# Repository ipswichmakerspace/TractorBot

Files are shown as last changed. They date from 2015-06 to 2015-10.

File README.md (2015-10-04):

# TractorBot 2014
Code and hardware files for TractorBot, the winner of the 2014 [PiWars](http://piwars.org) competition run by the CamJam team in Cambridge. The code, schematics and hardware files provided are exactly as the robot ran on the day of the 2014 competition. There is certainly room for improvement, and we expect this to be used as a solid base to start from, rather than a finished polished product. It worked for us, but your mileage may vary.

If you have any questions please use our [forums](http://forums.ipswichmakerspace.com) 

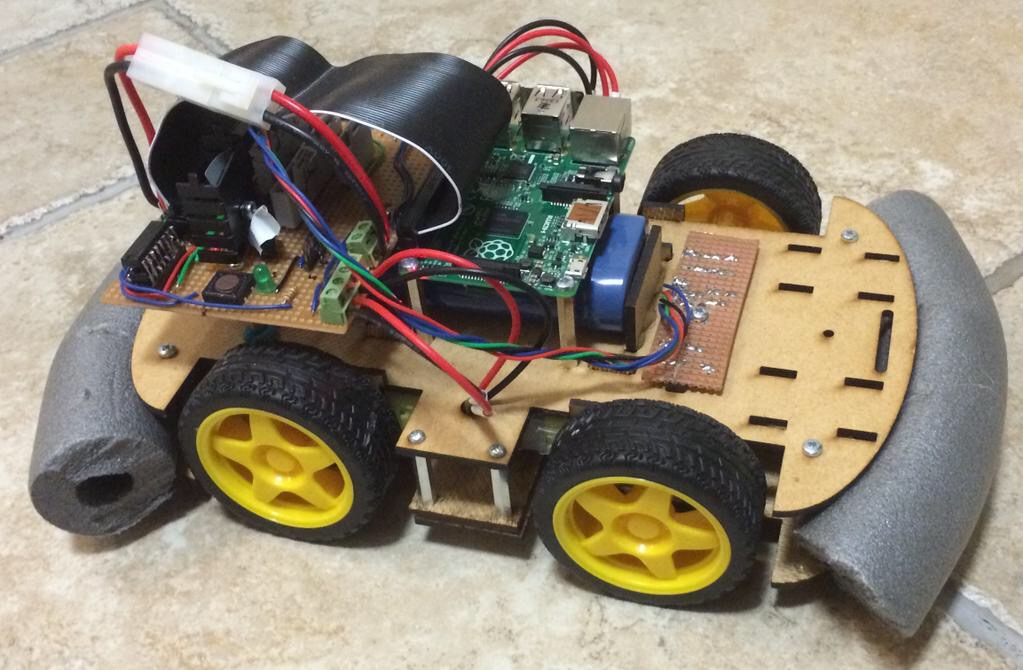
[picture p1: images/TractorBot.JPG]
TractorBot


The **hardware**, files of which can be found in the hardware folder are licensed under the CERN Open Hardware Licence v1.2, the license can be found in the directory /hardware/license. this is essentially an open source licence which can be used for all purposes provided attribution is given to Ipswich Makerspace.

The chassis is designed to be laser cut from a material measuring 3mm thick. Perspex could be used, but for cost we used hard board and this worked very well.

Our chassis was cut by [Cedarcroft Productions](http://www.cedarcroftproductions.com/) based in Ipswich.

Many of the parts for TractorBot were provided by our sponsor [Rapid Electronics](http://www.rapidonline.com/)

The code and schematics for the interface board are now in this repository.  We have kept the information short and to the point, for example we do not provide instructions for the construction of the chassis,  this is quite self explanitory.  However if we get a few requests for more information and if time allows we may build on this information.

For the electronics, including Fritzing diagrams, Ki-CAD schematics and information how it all works click [here](electronics/electronics.md)

For a description of the hardware click [here](hardware/hardware.md)

Hardware designed by Keith Ellis

Software written by Phil Willis in C++
on behalf of [Ipswich Makerspace](http://ipswichmakerspace.com)

----

If you have any queries or questions please raise on the Ipswich Makerspace [forums](http://forums.ipswichmakerspace.com/)

**TractorBot** is a Trademark of Ipswich Makerspace

This is provided on an "as-is" basis and all rights are reserved, no warranty is provided and no responsibility will be taken for any harm or damage caused whatsoever.

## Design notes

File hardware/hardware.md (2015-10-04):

#Hardware#

##General Description##
TractorBot was designed to be cheap, we competed in the £75 and under catergory, and we were very honest with out pricing.  As a result we built our own interface board [see electronics](../electronics/electronics.md), and designed and lasercut our own chassis.

The chassis was a simple design and consists of a single plate with four cheap motors attached to the plate with 'T' connection brackets.  We were always keen to do well in the obstacle course challege so we went with four wheel drive and kept the ground clearance as high as possible.  To aid the ground clearance we did not install a second plate beaneath the motors, instead, we installed a small strengthening plate between the four wheels.

The image below shows TractorBot during development. 

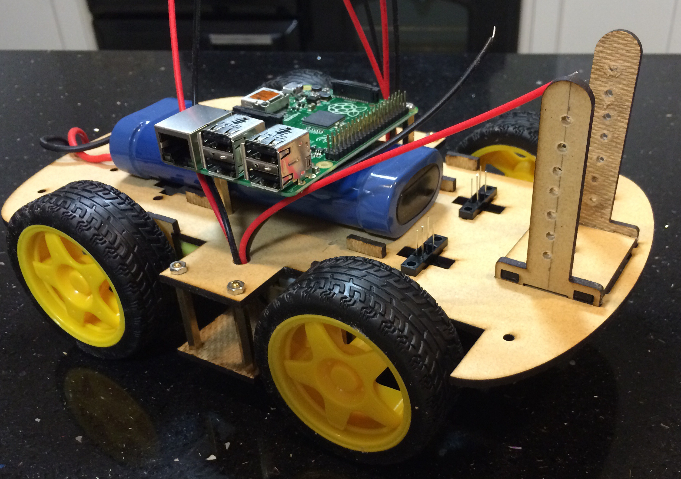
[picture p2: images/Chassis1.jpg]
Chassis


You can see the main plate, with the small strenghening plate below betwen the wheels, this was installed on 25mm long stand-offs.  On top of the plate there is a standard radio controlled car battery, which runs at 7.2v, the Raspoberry Pi was installed above the battery on stand-offs.  At the front we developed a universal mount system which allowed us to add and remove various sensors or attachments to suit each challenge.

The attachments we made are as follows:

* Ultrasonic sensor mount, we also mounted an IR distance sensor on this too.  Both for the proximity challenge

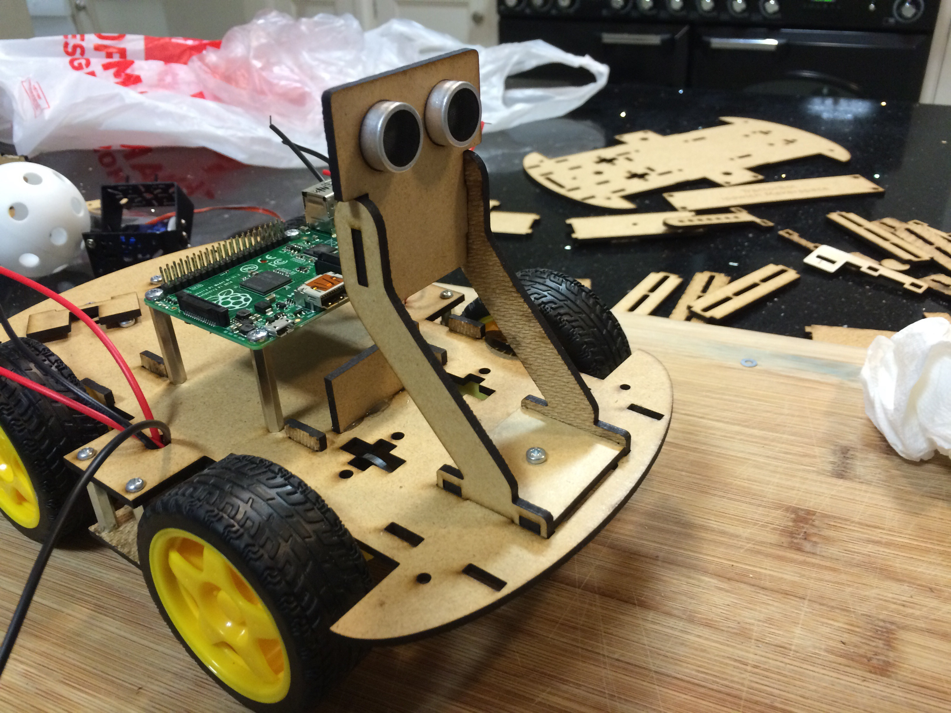
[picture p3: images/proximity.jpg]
Proximity


* Ball catcher, for the golf challenge

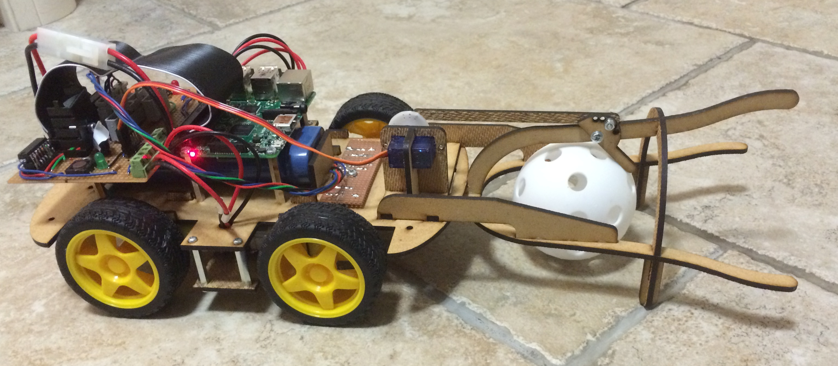
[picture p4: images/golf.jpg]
Golf


* Line following sensors, for the line following challenge

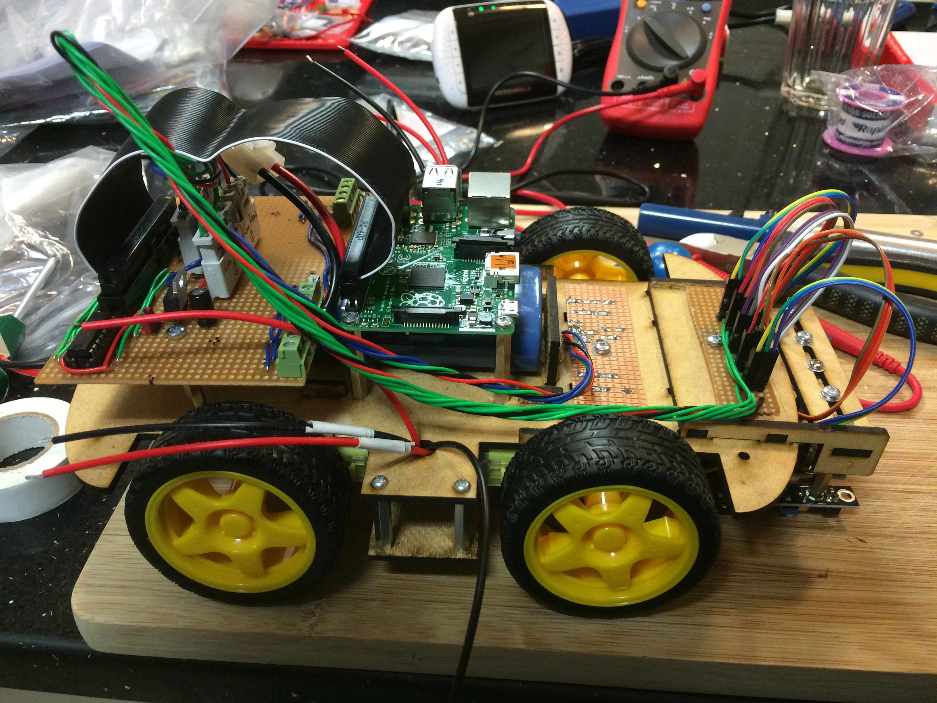
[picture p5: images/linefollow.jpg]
Line Folow


* Sumo suit, for the Sumo challenge

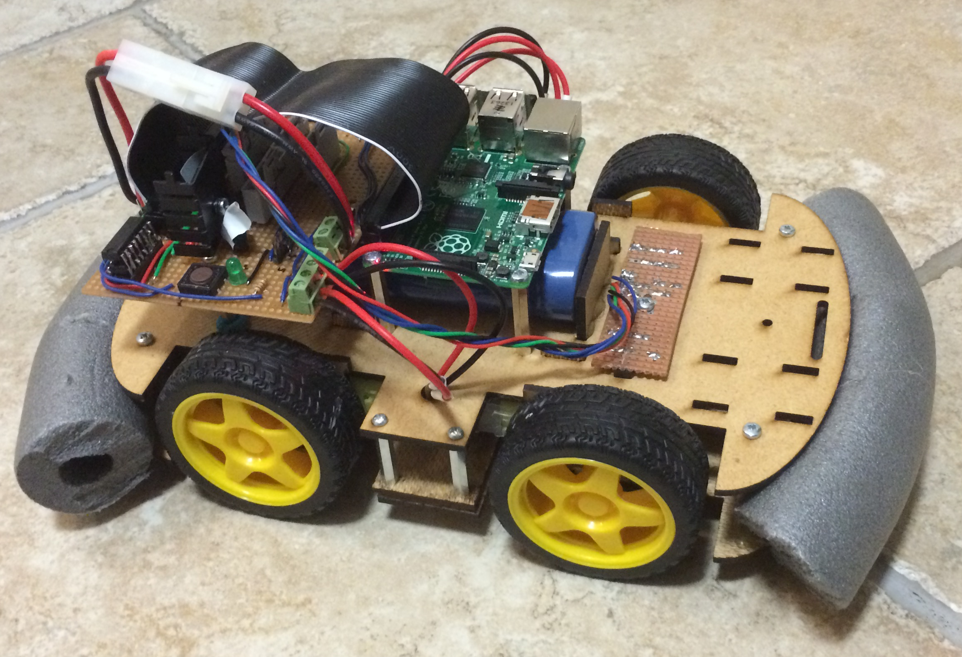
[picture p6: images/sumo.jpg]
Sumo


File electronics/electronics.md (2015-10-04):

#Electronics#

##Overview##
**TractorBot** electronics is contained on a main interface board.  The interface board features the following features:

- 20 x 2 shrouded header to allow connection to the Raspberry Pi with a 40 way ribbon cable
- 5 volt low dropout voltage regulator
- L293D motor driver
- two LED's and buttons to allow selection of mode - described in the software section
- terminal connectors to conect 7.2v RC car battery
- terminal connectors to connect four motors
- jumper to connect/disconnect power to the Pi
- various headers
    - serial debug connection
    - motor encoders
    - line follower sensors
    - ultra sonic sensor
    - IR object detection sensor
    - servo
    
We have provided the following information:

- A general description on how the the robot works (below)
- Interface board map, showing the features of the board, where they are and also Raspberry Pi pin numbers
- Fritzing file and image, this is not exactly the same as the board as entered into the compitition, mainly because we found it hard to find particualar components in Fritzing. We have also omitted the swithc to disable the rear motors, we did not use this feature in the competition, the robot ran in 4WD at all times.
- We also plan to provide Ki-CAD schematics, but these have not been produced yet.

It should be noted the this documentation for the electronics has been prepared approximately nine months after the interface boards were actually made.  The board got build over a number of weeks and was not planned in advace, therefore the layout is probably not optimum.

##Interface board##
The interface board is build on strip board, when using strip board is is often necessary to break the tracks to allow a single track to be used for two signals, particually the tracks connecting the 20 x 2 header has to be broken along the centre to prevent the two rows of pins from being connected.  All the breaks can be seen in the Fritzing file, but to make it clear I have provided a image of the strip board alone.

###Fritzing Stripboard layout###
showing broken tracks

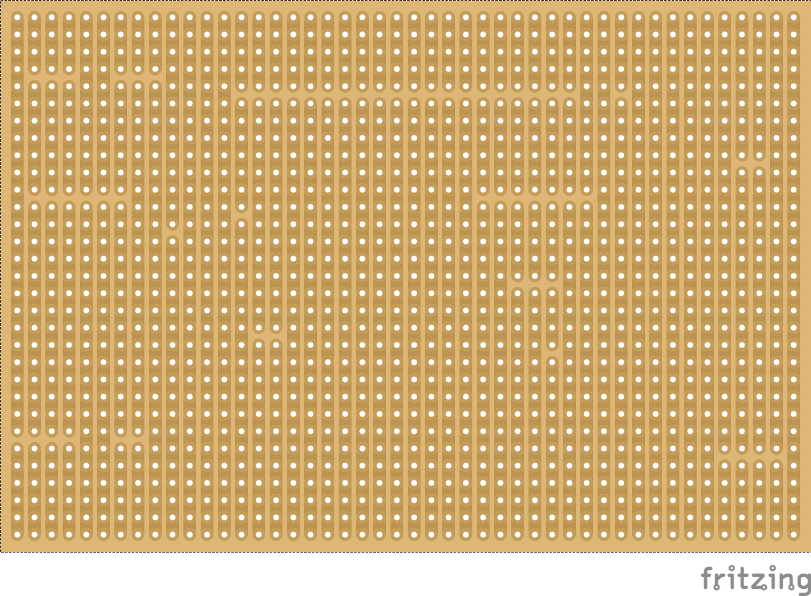
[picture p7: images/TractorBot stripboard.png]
stripbaord


###Fritzing interface board layout###
complete with all wiring

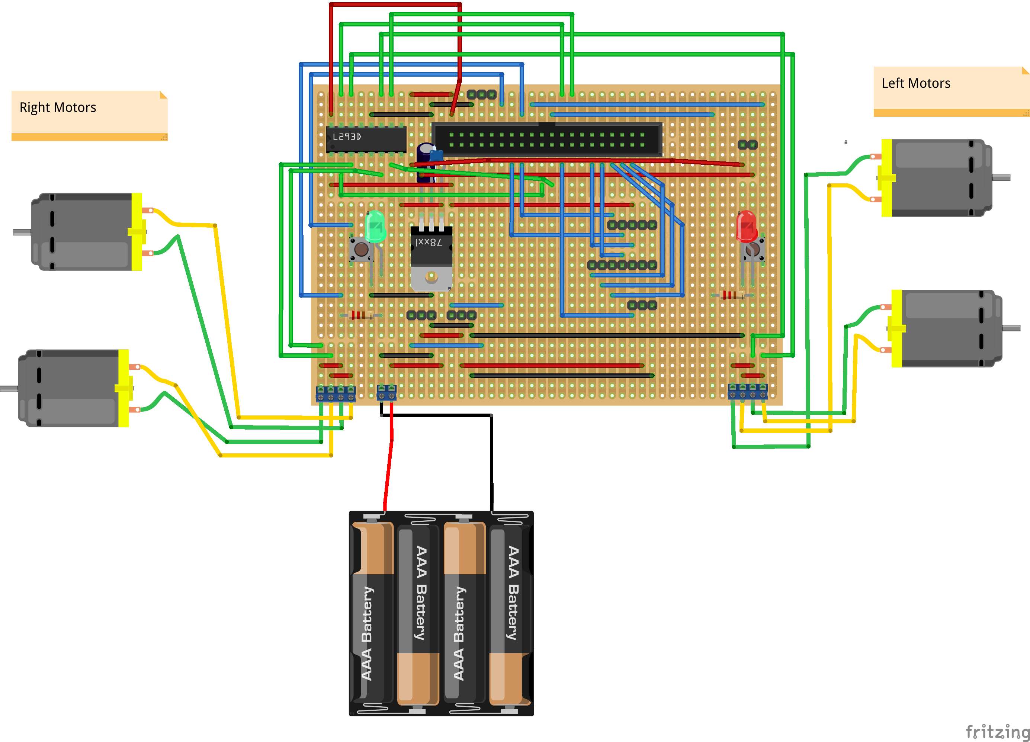
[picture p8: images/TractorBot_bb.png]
Interface board


###Interface board map###
showing header and terminal connection pin outs
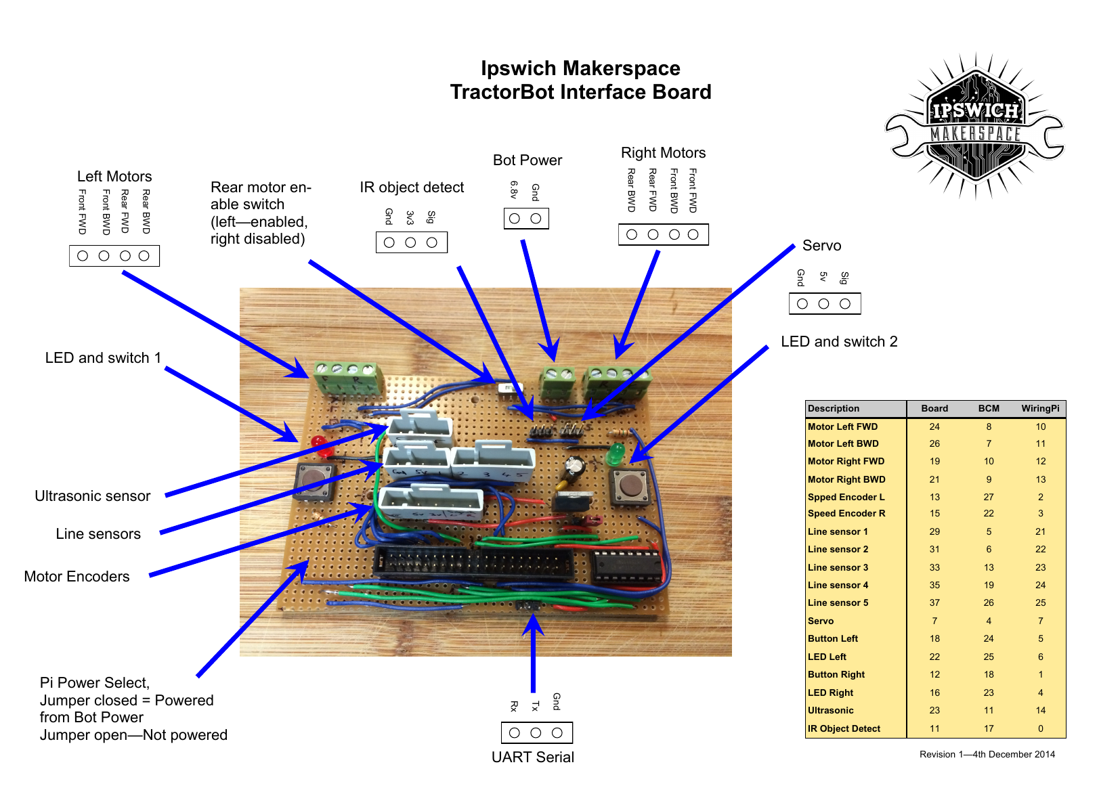
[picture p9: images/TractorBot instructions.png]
Interface board map


[Fritzing file](TractorBot.fzz), note this has been produced after the process of making the actual stripboard, I have done a thorough review to ensure as far as possible that it is correct but there may be a mistake which has been missed.  Please check carefully yourself before use.  I do not take any responsibility for a damaged Pi as a result of using this file.

##20 x 2 shrouded header##
I got this shrouded header and the ribbon cable from an Adafruit Pi cobbler, I think I got mine from [Pimoroni](http://shop.pimoroni.com/products/adafruit-pi-t-cobbler-plus-kit-breakout-for-raspberry-pi-b).  Pin one is shown on all images here to the top right, i.e the end closest to the motor driver is pin 1.  To break the tracks between the two rows of pins I used a stanley knife with a steel ruler and run the knife along the board several times to ensure I cut the tracks properly.  I also checked that each track had been cut using a multi meter on the continuity setting.  vThis should be done before the header is soldered, it would be very dificult to cur the tracks afterwards.

##5v voltage regulator##
To ensure we had enough power for the motors a 7.2 volt radio contorl car battery was used.  We got ours from [Rapid Electronics](http://www.rapidonline.com/Education/VEX-7-2V-Robot-Battery-NiMH-3000mAh-70-6237).  This ensured we had plenty of power for the motors but 7.2v would fry a Pi, to enable this battery to be powered from the same battery and to avoid putting an addition 5v battery on board we used a 5v voltage regulator.  This takes the 7.2v and puts out 5v for use by the Pi.  The voltage regulator is a thre pin device and can be seen adjacent to the right hand button and green LED.  

The part number we used was the National Semiconductor LM2940, data sheet can be found [here](7427.pdf), as can be seen on the data sheet this also requires two capacitors.  It will not work without the capacitors (trust me, I tried it). a 0.41 micro farrade is required between the Vin and ground and a 22 micro farrade capacitor is required between Vout and ground.

In our case, Vin will be the 7.2 volt supply and Vout will be the 5v coming out, which we then feed into the Pi.

##Motor driver##
We used a L293D motor driver to drive all four motors.  The current draw of the motors four motors is quite close to limits of the driver chip but it should be ok.  Pin 1 for the motor driver is to the top right as shown in the images, i.e. pin 1 is on the edge of the strip board.  The data sheet can be found [here](l293d.pdf).  There are many tutorials one the internet showing how to use these chips so I will not cover it here, sufice to say, it takes the low input from the Pi GPIO pins and out puts the 7.2v direct from the battery straight to the motor.

##LED's and buttons##
The interface board has two LED's and buttons.  These are used to navigate through the programs menu system.  The red button is pressed a number of times depending upon the mode required.  the red LED indicated how many times the button has been pressed by flashing.  The button adjacent to the green button selects the desired mode.  More about this will be in the software section.

##Terminals and headers##
All the pins are identified on the interface board map, shown above.  The only exeption being the jumper to contorl the power to the Pi.  I moved this after making the map to make it more accessable, however the Fritzing file and the label on the map are showin in the correct location.  To use this the 7.2v battery must be plugged in, then to power the Pi the jumper is placed on this header.  The Pi will be powered and boot up and automatically start the TractorBot program.

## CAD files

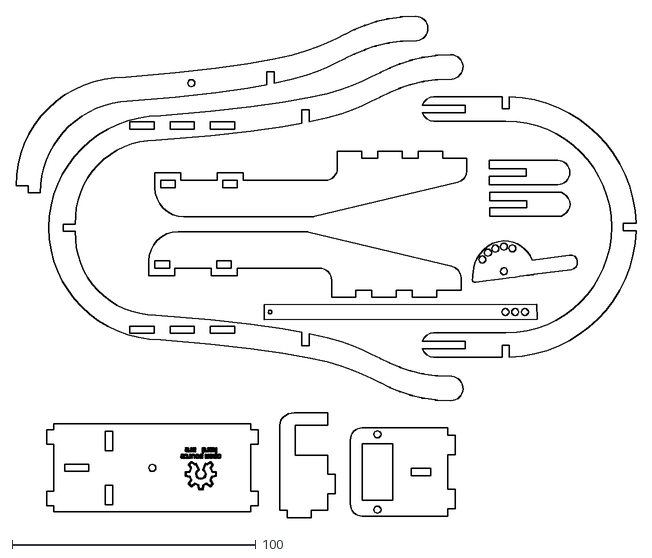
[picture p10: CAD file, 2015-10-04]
hardware/Source Files/Ball catcher.dxf
254.4 x 205.8

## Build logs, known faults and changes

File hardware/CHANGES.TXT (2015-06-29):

This is the original documentation.  If you make changes please detail them here and distribute this document with the modified files and the CERN OSH License v1.2

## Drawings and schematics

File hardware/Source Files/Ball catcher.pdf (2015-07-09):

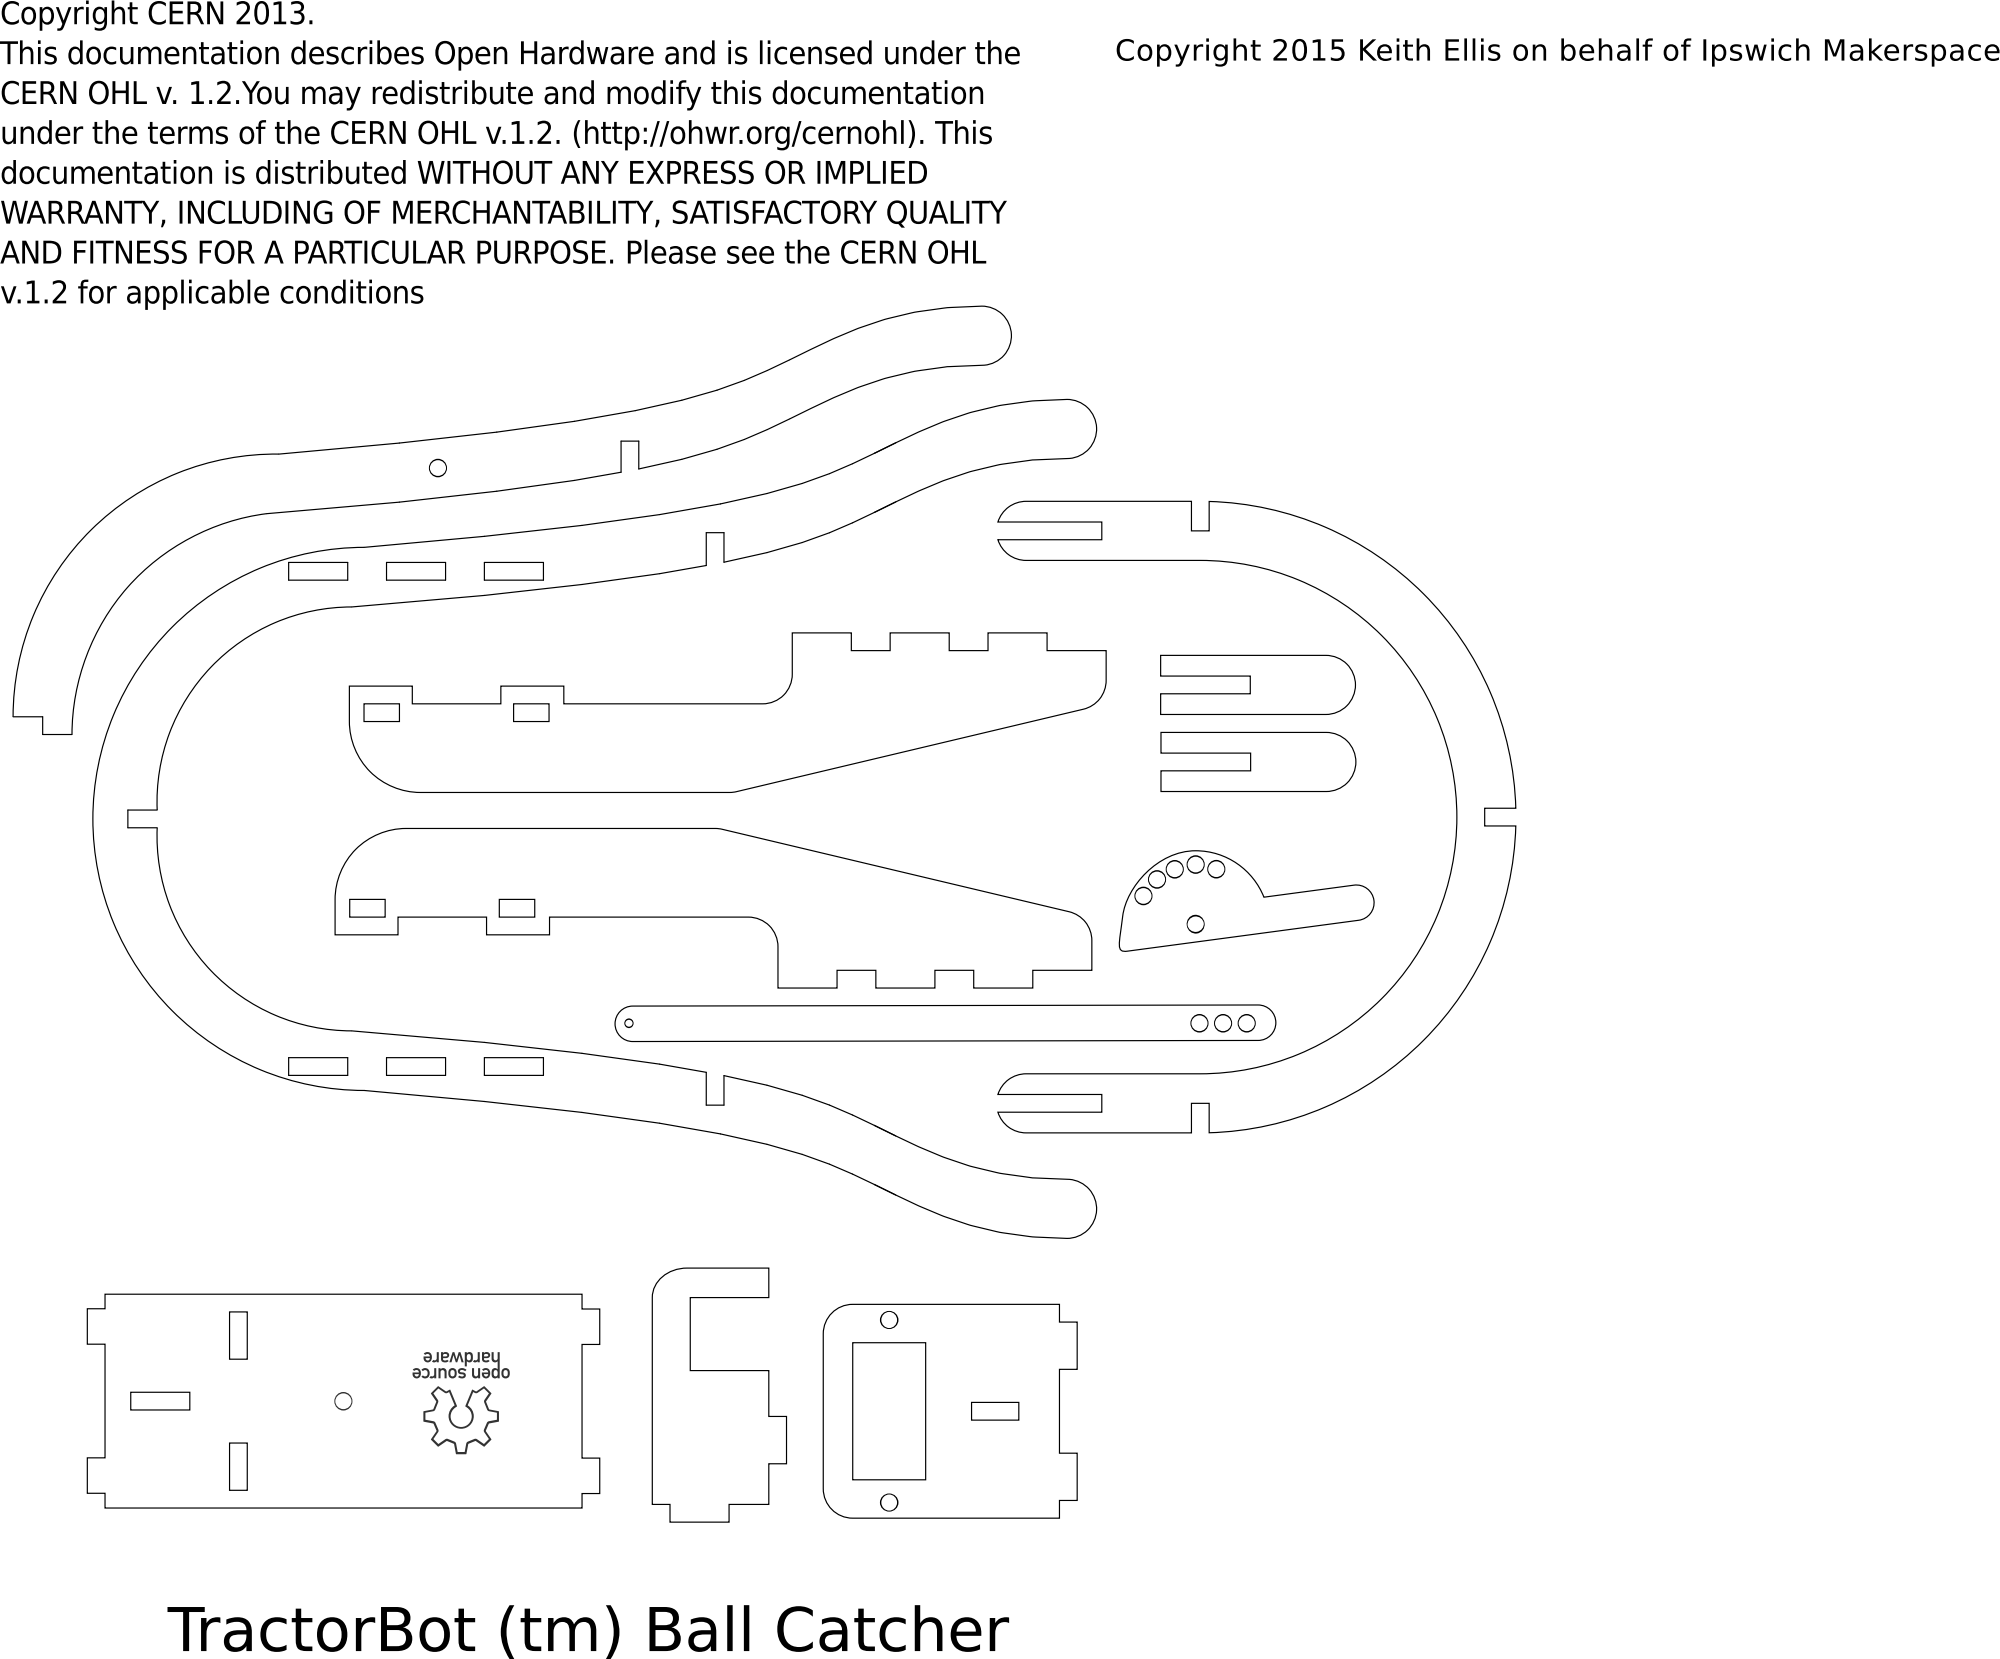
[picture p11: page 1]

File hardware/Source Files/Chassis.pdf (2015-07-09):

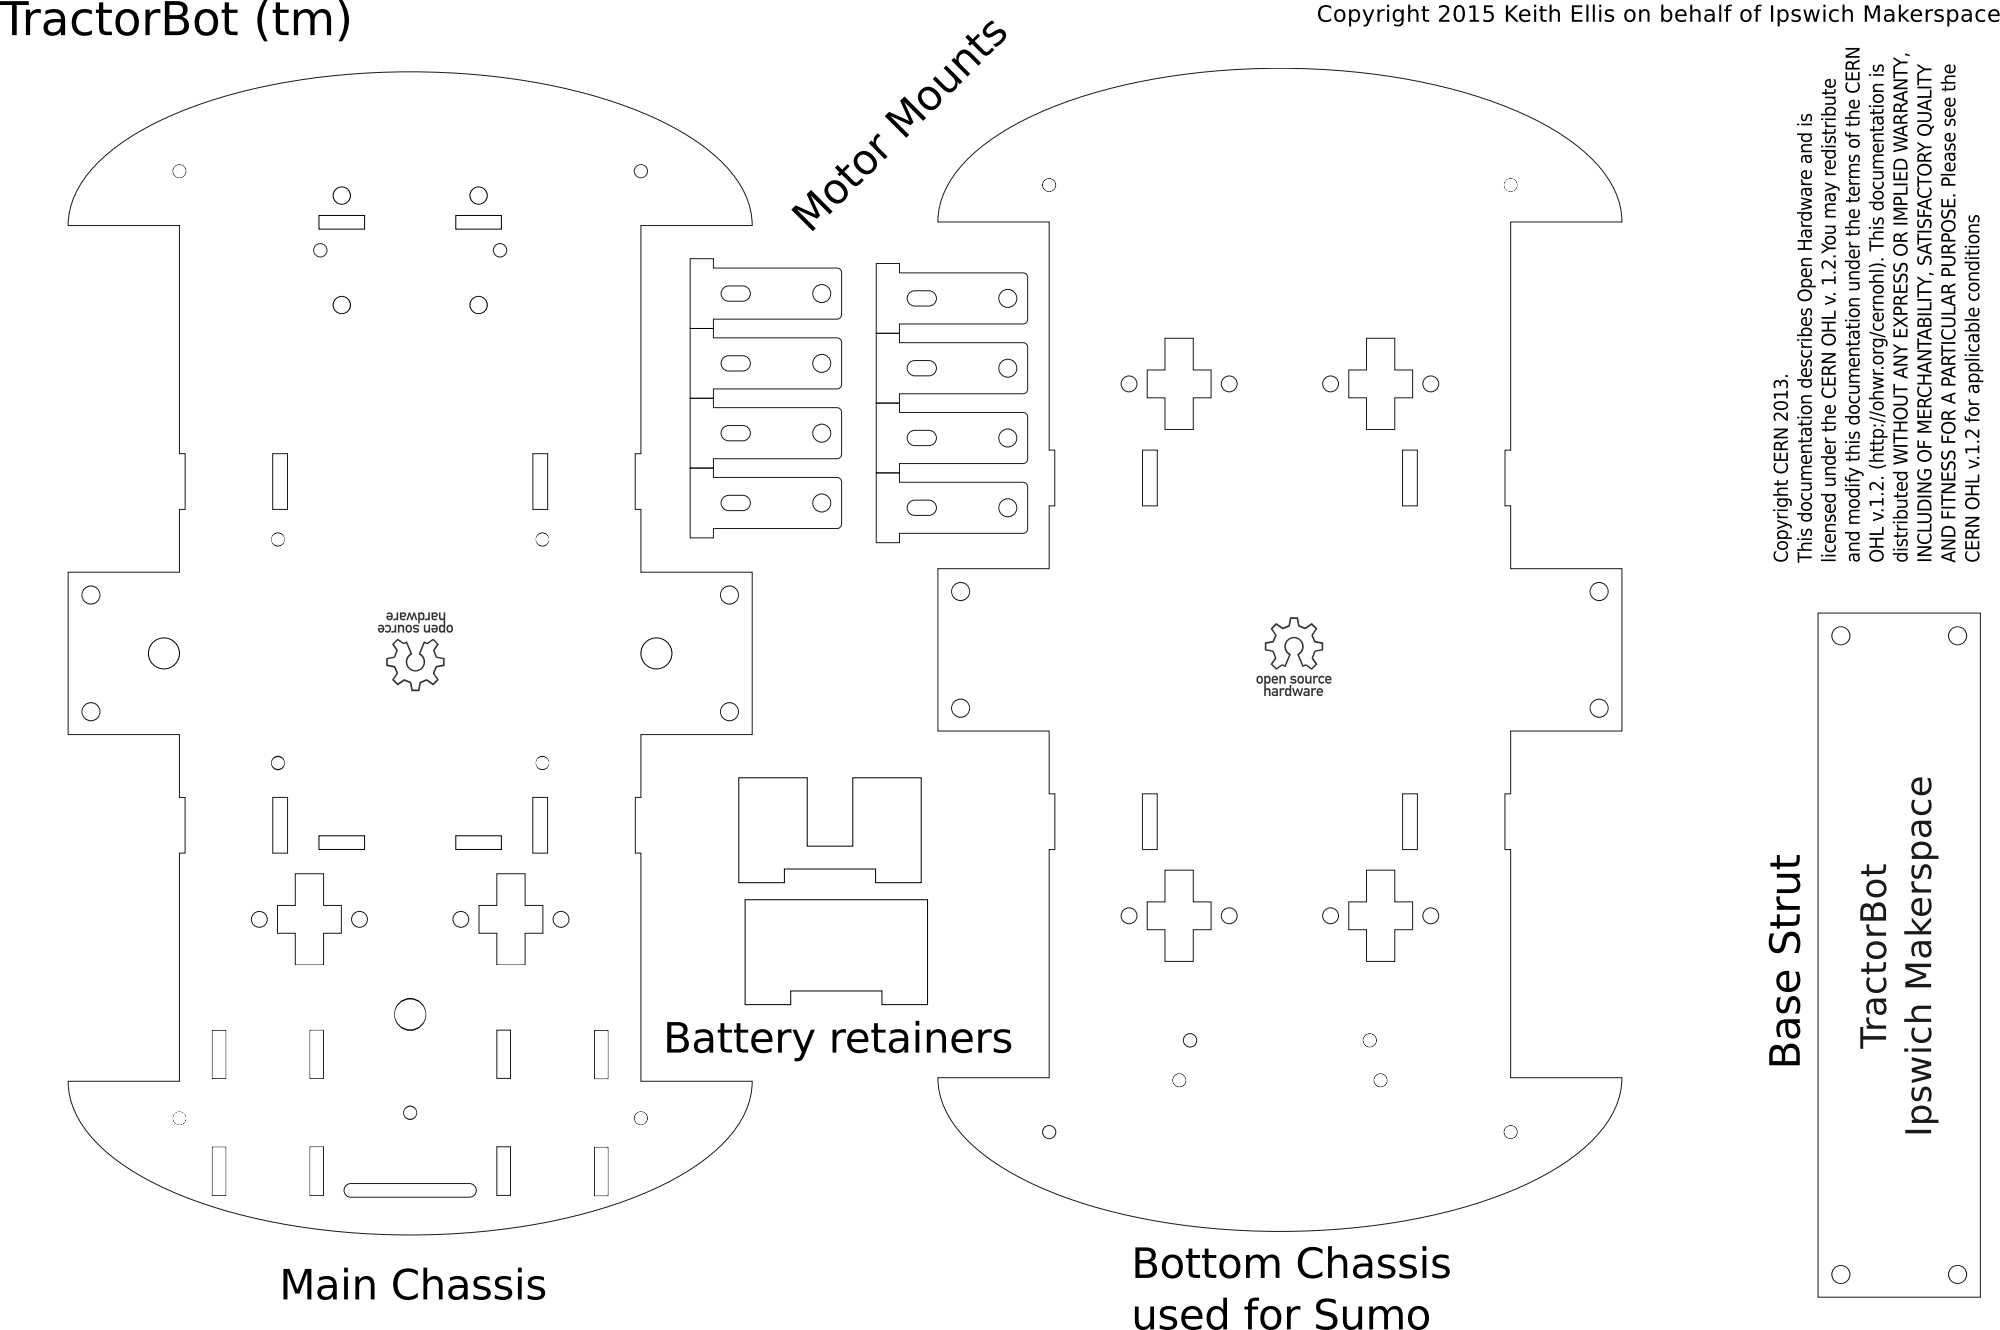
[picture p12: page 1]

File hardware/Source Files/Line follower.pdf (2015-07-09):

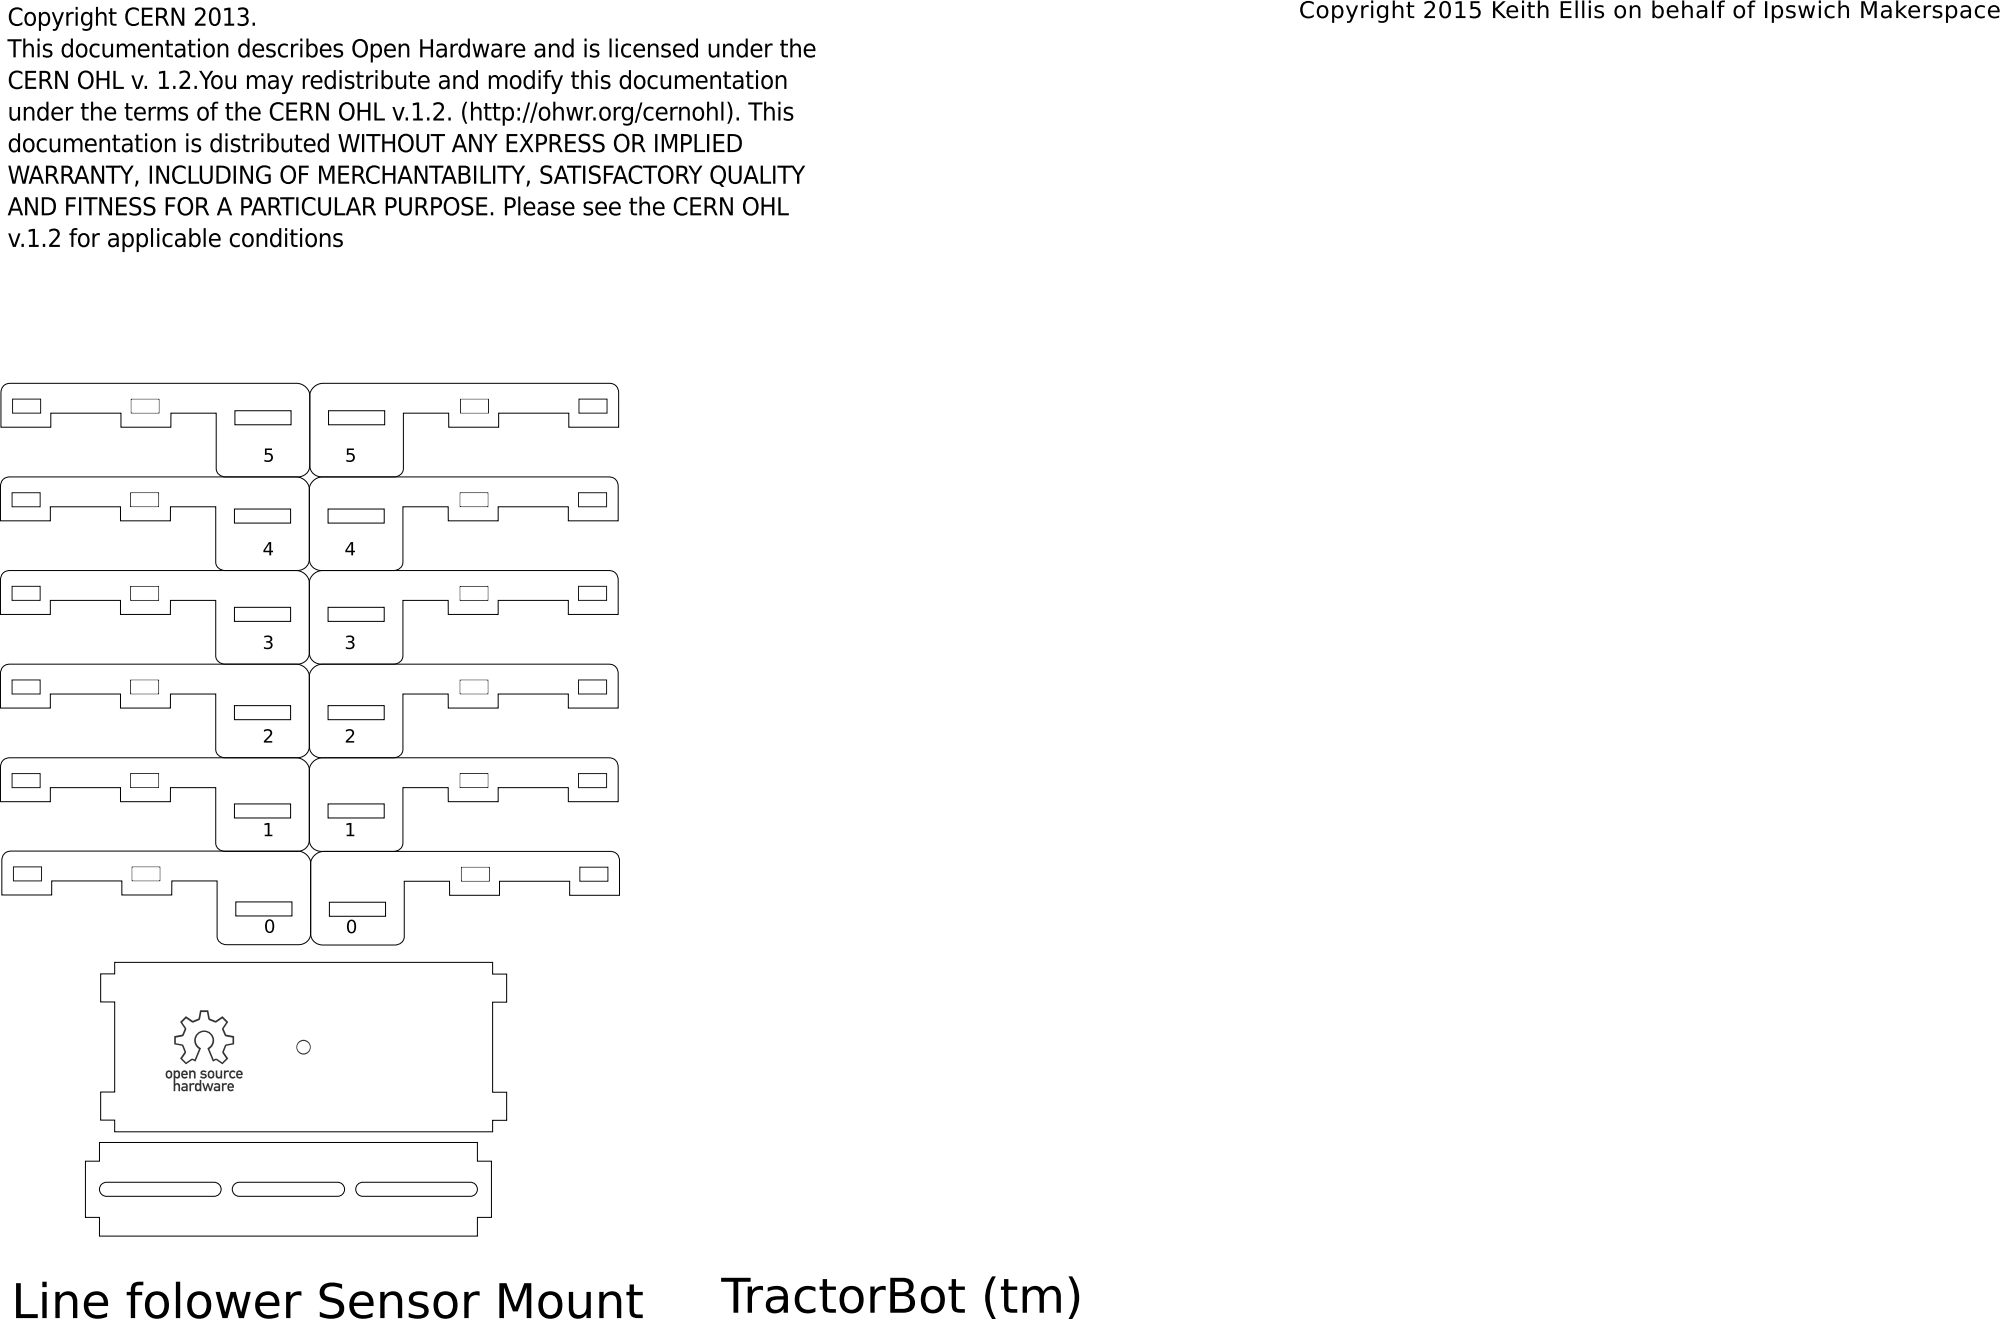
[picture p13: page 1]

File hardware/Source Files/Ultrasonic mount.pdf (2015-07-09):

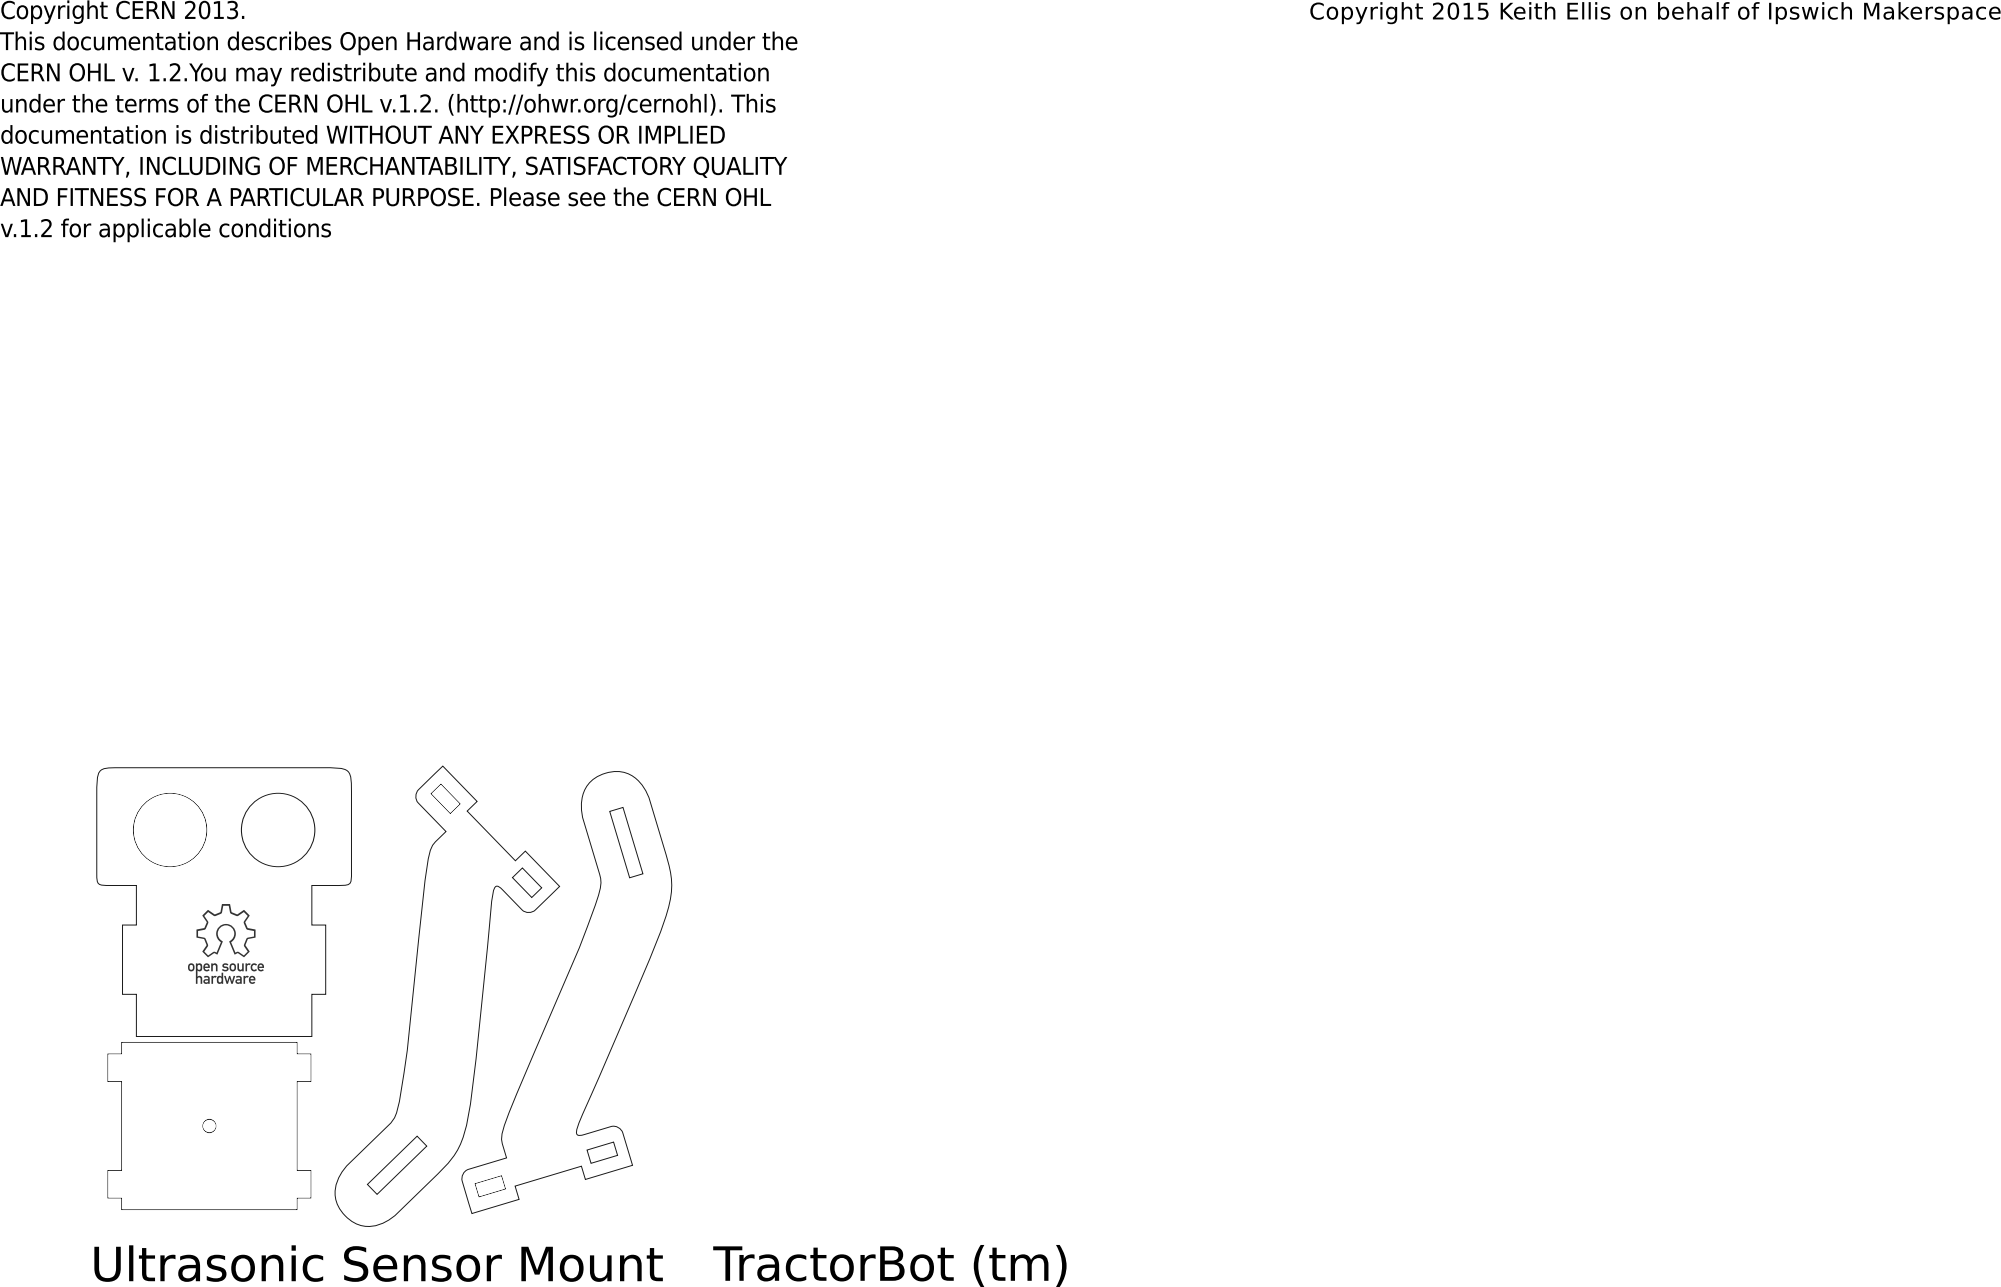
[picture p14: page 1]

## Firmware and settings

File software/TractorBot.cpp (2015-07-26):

/*
 * Copyright (C) 2014 Phil Willis
 *
 * Licensed under the Apache License, Version 2.0 (the "License");
 * you may not use this file except in compliance with the License.
 * You may obtain a copy of the License at
 *
 *      http://www.apache.org/licenses/LICENSE-2.0
 *
 * Unless required by applicable law or agreed to in writing, software
 * distributed under the License is distributed on an "AS IS" BASIS,
 * WITHOUT WARRANTIES OR CONDITIONS OF ANY KIND, either express or implied.
 * See the License for the specific language governing permissions and
 * limitations under the License.
 */

#include <iostream>
#include <string>
#include <vector>
#include <stdio.h>
#include <math.h>

#include <stdlib.h>
#include <sys/time.h>
#include <sys/types.h>
#include <unistd.h>
#include <fcntl.h>
#include <termios.h>

// Support for Wii controller
#include <bluetooth/bluetooth.h>
#include <cwiid.h>

// Wiring Pi a nice C lib for accessing the GPIO 
#include <wiringPi.h>
#include <softPwm.h>

using namespace std;

// Our motor control pins
#define LEFT_MOTOR_FWD   12
#define RIGHT_MOTOR_FWD  10
#define LEFT_MOTOR_BWD   13
#define RIGHT_MOTOR_BWD  11

// The servo pin ( not used directly but defined to reserve use with ServoBlaster )
#define SERVO 			7

// Red button and LED for human feed back
#define BUTTON 			5
#define LED 			6

// Line follower sensors
#define LINE_FARLEFT 	21
#define LINE_NEARLEFT 	22
#define LINE_CENTER 	23
#define LINE_NEARRIGHT  24
#define LINE_FARRIGHT 	25

// Pin for Ping and Pong from ultra sonic sensor
#define SONAR 			14

// Slotted encoders on left and right drive wheels
#define ENCODER_LEFT 	2
#define ENCODER_RIGHT 	3

//Backup IR proximity sensor
#define SENSOR 0

// As close (mm) as we dare ( including the part of the bot in front of the sensor )
#define TARGETDISTANCE 80.0

#define ALLSTOP -99999
#define INVALID 99999

#define WIDTH 320
#define SAMPLEWIDTH 160
#define HEIGHT 50
#define SAMPLEHEIGHT 25

#define TARGETAREA 800

// States used by proximity challenge, ultra sonic detector is checked 4 times to ensure a reasonable reading
enum class State
{
		Moving,
		FirstMeasure,
		SecondMeasure,
		ThirdMeasure,
		Done	
};

// Variables used in call backs and accessed in the main thread.
static volatile int leftCount = 0;
static volatile int rightCount = 0;

static volatile int startTime = 0;
static volatile int endTime = 0; 
static volatile int pulseLength = INVALID;
static volatile bool runProximity = false;

static volatile bool runThreePointTurn = false;

static volatile bool launch = false;
static volatile bool running = true; 
static volatile int presses = 0;
static volatile bool inMenu = true;

// Basic motor speeds 
unsigned int highSpeed = 255;
unsigned int lowSpeed = 70;

int imageWidth = SAMPLEWIDTH;

void remoteControl();
void lineFollower();
void proximity();
void threePointTurn();
void leaveMenu();
void shutdown();


void setLed( int l1 )
{
	digitalWrite (LED, l1);	
}

int CalcSpeed(double diff) 
{
	const double lowLimit = lowSpeed;
	const double highLimit = highSpeed;
	
	diff = std::abs((long)diff);
	
    int speed =  int( (highLimit * ( diff / imageWidth )) + lowLimit );


    return speed;    
}

char getKey() 
{
	fd_set set;
	struct timeval tv;

	tv.tv_sec = 0;
	tv.tv_usec = 10;

	FD_ZERO( &set );
	FD_SET( fileno( stdin ), &set );

	int res = select( fileno( stdin )+1, &set, NULL, NULL, &tv );

	if( res > 0 )
	{
		char c;
		printf( "Input available\n" );
		read( fileno( stdin ), &c, 1 );
		return c;
	}
	else if( res < 0 )
	{
		perror( "select error" );
		return 0;
	}
	return 0;
}

void TurnRight(double diff) 
{       
    int speed = CalcSpeed( diff );     
    softPwmWrite (RIGHT_MOTOR_FWD, 0);
    softPwmWrite (RIGHT_MOTOR_BWD, 0);
    softPwmWrite (LEFT_MOTOR_FWD, speed);
    softPwmWrite (LEFT_MOTOR_BWD, 0); 
}

void TurnLeft(double diff) 
{    
    int speed = CalcSpeed( diff ); 
    softPwmWrite (RIGHT_MOTOR_FWD, speed);
    softPwmWrite (RIGHT_MOTOR_BWD, 0);
    softPwmWrite (LEFT_MOTOR_FWD, 0);
    softPwmWrite (LEFT_MOTOR_BWD, 0);    
}

void SharpRight(double diff)
{
    int speed = CalcSpeed( diff );     
    softPwmWrite (RIGHT_MOTOR_FWD, 0);
    softPwmWrite (RIGHT_MOTOR_BWD, speed);
    softPwmWrite (LEFT_MOTOR_FWD, speed);
    softPwmWrite (LEFT_MOTOR_BWD, 0);    
}

void SharpLeft(double diff) 
{
    int speed = CalcSpeed( diff ); 
    softPwmWrite (RIGHT_MOTOR_FWD, speed);
    softPwmWrite (RIGHT_MOTOR_BWD, 0);
    softPwmWrite (LEFT_MOTOR_FWD, 0);
    softPwmWrite (LEFT_MOTOR_BWD, speed);    
}

void Straight( int speed )
{    
    softPwmWrite (RIGHT_MOTOR_FWD, speed );
    softPwmWrite (RIGHT_MOTOR_BWD, 0);
    softPwmWrite (LEFT_MOTOR_FWD, speed );
    softPwmWrite (LEFT_MOTOR_BWD, 0);    
}

void Reverse( int speed )
{    
    softPwmWrite (RIGHT_MOTOR_FWD, 0);
    softPwmWrite (RIGHT_MOTOR_BWD, speed);
    softPwmWrite (LEFT_MOTOR_FWD, 0);
    softPwmWrite (LEFT_MOTOR_BWD, speed);    
}

void Stop() 
{    
    softPwmWrite (RIGHT_MOTOR_FWD, 0);
    softPwmWrite (RIGHT_MOTOR_BWD, 0);
    softPwmWrite (LEFT_MOTOR_FWD, 0);
    softPwmWrite (LEFT_MOTOR_BWD, 0); 
}

void SetRightMotor(int speed)
{
	if( speed < 0 ) 
	{
		speed = max(speed * -1, 255);
		softPwmWrite (RIGHT_MOTOR_FWD, 0 );
		softPwmWrite (RIGHT_MOTOR_BWD, speed );	
	}
	else
	{
		speed = max(speed, 255);
		softPwmWrite (RIGHT_MOTOR_FWD, speed );
		softPwmWrite (RIGHT_MOTOR_BWD, 0 );
	}
}

void SetLeftMotor(int speed)
{
	if( speed < 0 ) 
	{
		speed = max(speed * -1, 255);
		softPwmWrite (LEFT_MOTOR_FWD, 0);
		softPwmWrite (LEFT_MOTOR_BWD, speed );
	}
	else
	{
		speed = max(speed, 255);
		softPwmWrite (LEFT_MOTOR_FWD, speed );
		softPwmWrite (LEFT_MOTOR_BWD, 0);	
	}
}

// Flash an LED a given number of times with the given delay
void flashLED(int times, int speed)
{		
	for(int i = 0; i < times; i++)
	{
		setLed(1);
		delay(speed);
		setLed(0);
		delay(speed);
	}	
}

// If the number of times has changed then flash the new number of times
// (Used to confirm actions)
void blinkLED(int times, int speed)
{	
	static int previous = 0;
	if( times != previous )
	{
		setLed(0);
		delay(500);	
		flashLED(times, speed);
	}
	else
		setLed(0);
		
	previous = times;		
}

// Wait for a pin for a given number of micro-seconds to be either HIGH or LOW depending on the value of level 
long waitforpin(int pin, int level, long timeout)  
{  
   struct timeval now, start;  
   int done;  
   long micros;  
   gettimeofday(&start, NULL);  
   micros = 0;  
   done=0;  
   while (!done)  
   {  
	   gettimeofday(&now, NULL);      
	   micros = ((now.tv_sec - start.tv_sec)*1000000L) + (now.tv_usec - start.tv_usec);  
	   if (micros > timeout) done = 1;	    
	   if (digitalRead(pin) == level) done = 1;  
   }  
   return micros;  
}  

// Test for a press of a button and respond depending on duration
// A press of less than one second will increment the counter
// A press of between two and five seconds with reset the counter
// A press of more than 5 seconds will start a specific challenge function
void countPresses()
{
	setLed(1);
	// Button pulls pin low so we wait for it to go high again.
	long micros = waitforpin(BUTTON,HIGH,30000000L);
	setLed(0);
	
	// A short press might be noise or double bounce	
	if (micros < 10 )
		return;
	// Less than a second is a good press
	if ( micros < 1000000L )
		presses++;
	// More than two seconds but less than five reset the counter
	else if ( micros > 2000000L && micros < 5000000L)
		presses = 0;
	// More than five seconds and the function can be launched
	else if ( micros > 5000000L )
		launch = true;
		
	printf("countPresses: %d\n",presses);
}	

// Start the function in response to a sepcific number of presses
void launchFunction(int presses)
{
	printf("launchFunction: %d\n",presses);
	switch(presses)
	{
		case 1:
			proximity();			
			break;
		case 2:
			lineFollower();
			break;
		case 3:
			remoteControl();
			break;
		case 4:
			threePointTurn();
			break;			
		case 5:
			leaveMenu();
			break;
		case 6:
			shutdown();
		default:
			fprintf(stderr, "Warn: Application not defined\n"); 
	}	
}

// ****************************************************************************
//
// Main function to Shutdown the Pi 
//
// ****************************************************************************
void shutdown()
{	
	// sync the file system and start the shutdown process
	system("sync;halt");
	// Flash the LED as we shutdown we may or may not get to 10 flashes
	flashLED( 10, 250 );
	exit(0);
}

// ****************************************************************************
//
// Main function to exit main menu
//
// ****************************************************************************
void leaveMenu()
{
	inMenu = false;
}

// ****************************************************************************
//
// Main function for three point turn challenge
//
// ****************************************************************************
void threePointTurn()
{
	runThreePointTurn = true;
	
	runThreePointTurn = false;
}

//
// A call back for the Wii controller using cwidd library
//
void cwiid_callback(cwiid_wiimote_t *wiimote, int mesg_count,
                    union cwiid_mesg mesg[], struct timespec *timestamp)
{
	int i;
	int leftStick;
	int rightStick;
			
	for (i=0; i < mesg_count; i++)
	{
		switch (mesg[i].type) {
		case CWIID_MESG_NUNCHUK:			
		case CWIID_MESG_STATUS:
		case CWIID_MESG_BTN:
		case CWIID_MESG_ACC:
		case CWIID_MESG_IR:
			break;			
		case CWIID_MESG_CLASSIC:
			printf("button: %4X\n",mesg[i].classic_mesg.buttons);
			// Wii classic controller uses two proportional sticks and many buttons
			if( mesg[i].classic_mesg.buttons == 0x0001 )
			{
				// Use UP on the dpad to open ball catcher
				//printf("Servo forward\n");
				system("echo 0=94% > /dev/servoblaster");
			}
			else if( mesg[i].classic_mesg.buttons == 0x4000 )
			{
				// Use DOWN on the dpad to close ball catcher
				//printf("Servo back\n");
				system("echo 0=62% > /dev/servoblaster");
			}
			else if( mesg[i].classic_mesg.buttons == 0x800 )
			{
				// Use HOME stop and return to main menu
				printf("Stop and return to main menu\n");
				running = false;
			}
			
			
			// Left stick Left = 5, Right = 54, Centre = 30
			// Right stick Up = 29, Down = 2, Centre = 16
			// Proportional joy sticks for turning, forward and reverse
			leftStick = mesg[i].classic_mesg.l_stick[CWIID_X];
			rightStick = mesg[i].classic_mesg.r_stick[CWIID_Y];
			if(leftStick < 14 )
				SharpRight( SAMPLEWIDTH );
			else if( leftStick < 28 )
				TurnRight( SAMPLEWIDTH );
			else if( leftStick > 42 )
				SharpLeft( SAMPLEWIDTH );
			else if( leftStick > 32 )
				TurnLeft( SAMPLEWIDTH );
			else if( rightStick < 14 )							
				Reverse( int(255 * (16 - rightStick)/14));			
			else if( rightStick > 18 )
				Straight( int( 255 * (rightStick-18)/11)) ;
			else	
				Stop();
			break;
			
		case CWIID_MESG_BALANCE:
		case CWIID_MESG_MOTIONPLUS:
		case CWIID_MESG_ERROR:
		case CWIID_MESG_UNKNOWN:
			break;
		default:
			printf("Unknown Report");
			break;
		}
	}
}	
	
// ****************************************************************************
//
// Main function for the remote control challenges
//
// ****************************************************************************
void remoteControl()
{	
	cwiid_wiimote_t *wiimote;	/* wiimote handle */
	//struct cwiid_state state;	/* wiimote state */
	bdaddr_t bdaddr = {{0, 0, 0, 0, 0, 0}};   //* BDADDR_ANY;	/* bluetooth device address */

	char button_state;
	// First pair with the Wiimote
	printf("Put Wiimote in discoverable mode now (press 1+2)...\n");
	flashLED( 1, 1000 );  
	if (!(wiimote = cwiid_open(&bdaddr, 0))) {
		fprintf(stderr, "Unable to connect to wiimote\nReturn to main menu\n");
		flashLED( 5, 250 );
		return;
	}

	// Buzz the Wiimote to confirm pairing 	
	cwiid_set_rumble(wiimote, 1);
	sleep(1);
	cwiid_set_rumble(wiimote, 0);  

	// Set a call back for messages from the Wiimote
	if (cwiid_set_mesg_callback(wiimote, cwiid_callback))
	{
		fprintf(stderr, "Unable to set message callback\n");
		flashLED( 5, 500 );
		return;
	}

	// Set the reporting mode from the Wimote
	if (cwiid_set_rpt_mode(wiimote, CWIID_RPT_EXT))
	{
		fprintf(stderr, "Error setting report mode\n");
		flashLED( 5, 500 );
		return;	
	}

	// Finally enable messages from the Wiimote
	if (cwiid_enable(wiimote, CWIID_FLAG_MESG_IFC))
	{
		fprintf(stderr, "Error enabling messages\n");
		flashLED( 5, 500 );
		return;
	}

	running = true;
	// Enter loop and listen for a key press which will cause the function to exit
	// or "running" may be set false by the Wii call back
	while( running )
	{
		button_state = getKey();		
		if(button_state == 'x') 
		{  	  
			Stop();    
			running = false;
		}		
		sleep(1);
	}

	// Disable our Wii functions
	if(cwiid_disable(wiimote, CWIID_FLAG_MESG_IFC)) 
	{
		fprintf(stderr, "Error disabling messages\n");
	}

	// Finally shutdown the Wii controller
	if (cwiid_close(wiimote)) 
	{
		fprintf(stderr, "Error on wiimote disconnect\n");		
	}
}

//The sensors values are read in and converted to a binary value to help visualize the line position under the sensors.
//00100 represents the robot centered over the line
//10000 means the robot is to the right of the line
//00001 means the robot is to the left of the line
//
// The above value is mapped to a range 5 to -5, the maximum and minimum value depending on the previous position.
int GetPosition(int prev) 
{	
	int farLeft = digitalRead(LINE_FARLEFT);
	int nearLeft = digitalRead(LINE_NEARLEFT);
	int center = digitalRead(LINE_CENTER);
	int nearRight = digitalRead(LINE_NEARRIGHT);
	int farRight = digitalRead(LINE_FARRIGHT);
	
	printf("raw %d %d %d %d %d\n",farLeft,nearLeft,center,nearRight,farRight);
	
	int raw = (16 * farLeft) + (8 * nearLeft) + (4 * center) + (2 * nearRight) + farRight;
	
	//printf("raw %d \n",raw);
	
	// 10000 16 -4
	// 11000 24 -3
	// 01000 8	-2
	// 01100 12	-1
	// 00100 4	 0
	// 00110 6	+1
	// 00010 2	+2
	// 00011 3	+3
	// 00001 1	+4
	
	
	switch(raw) 
	{
		case 16:
		return -4;
		case 24:
		return -3;
		case 8:
		return -2;
		case 12:
		return -1;
		case 4:
		return 0;
		case 6:
		return 1;
		case 2:
		return 2;
		case 3:
		return 3;
		case 1:
		return 4;
	}
	
	if( raw == 0 && prev > 0 )
		return 5;
	else if	( raw == 0 && prev < 0 )
		return -5;		
		
	return 5;
}

// ****************************************************************************
//
// Main function for the line follower challenge
//
// ****************************************************************************
void lineFollower()
{
	flashLED( 2, 1000 );
	
	int previous = 0;
	int prevDiff = 0;
								//tried 2 0 0,3 0 0,1.5 0 1.5,1.5 0 1.8,1.5 0 2,1.2 0 2,1.2 0 2.4,1.2 0 2.8,1.2 0 2.2,1.2 0 2.4,1.0 0 2.4,0.8 0 2.4*, speed at 150
	const double Kp = 0.9;    	//speed 100, 1.8 0 0*, 1.8 0 1, 1.8 0 3.0, 1.8 0 4.0, 1.8 0 5.0, 0.9 0 0.9
	const double Ki = 0;		//speed 80, 0.9 0.0 1.4, 0.9 0.0 1.0, 0.9 0.0 1.4, 0.9 0.0 2.2, 0.9 0.0 4.4
	const double Kd = 0.9;

	double proportional = 0;

	double integral = 0;        

	double rateOfChange = 0;

	double derivative = 0;

	double control = 0;

	running = true;
	while (running) 
	{
		// PID control of motors 
		int position = GetPosition(previous);    
		previous = position;
			   
		int target = 0;    
		int diff = target - position;    

		proportional = diff * Kp;

		integral = (integral + diff) * Ki;        

		rateOfChange = diff - prevDiff;

		derivative = rateOfChange * Kd;    

		control = proportional + integral + derivative;
			
		//printf("Control %f\n",control);

		//if(control < 0)
			//printf("Will turn left\n");
		//else if(control > 0)
			//printf("Will turn right\n");
		//else
			//printf("Will go straight\n");

		int leftSpeed = int(80 + (control * +20));
		int rightSpeed = int(80 + (control * -20));

		printf("Left %d, Right %d\n",leftSpeed,rightSpeed);
			
		SetRightMotor(rightSpeed);
		SetLeftMotor(leftSpeed);		

		char button_state = getKey();

		if(button_state == 'x' || digitalRead(BUTTON) == LOW ) {  	  
			Stop();    
			running = false;
		}
	}
}

// Handler for the echo pulse
void echoStart()
{	
	//A rising edge has been seen so wait for it to go low
	pulseLength = waitforpin(SONAR, LOW, 60000L); /* 60 ms timeout */  
	if( pulseLength > 59999 ) pulseLength = INVALID;		
}

// Handler to increment the left counter on each left encoder pulse
void countLeftEncoder()
{
		leftCount++;
}

// Handler to increment the right counter on each right encoder pulse
void countRightEncoder()
{
		rightCount++;
}

// Each time we get a good reading increase the feel good factor about the reading
State IncreaseState( State state)
{
	switch(state)
	{
		case State::Moving:
			return State::FirstMeasure;
		case State::FirstMeasure:
			return State::SecondMeasure;
		case State::SecondMeasure:
			return State::ThirdMeasure;
		case State::ThirdMeasure:
			return State::Done;	
		case State::Done:
			return State::Done;	
	}
	return state;
}

// Each time we get a poor reading decrease the feel good factor about the reading
State DecreaseState( State state)
{
	switch(state)
	{		
		case State::ThirdMeasure:
			return State::SecondMeasure;
		case State::SecondMeasure:
			return State::FirstMeasure;
		case State::FirstMeasure:
			return State::Moving;
		case State::Moving:
			return State::Moving;
		// We never reach the state but the complier likes us to cover all the bases (states!)
		case State::Done:
			return State::Done;	
	}
	return state;
}

// Create a ping pulse
void ping()
{
	pulseLength = INVALID;
	// Ping the sensor
	pinMode(SONAR, OUTPUT);  
	digitalWrite(SONAR,1);
	usleep(10);
	digitalWrite(SONAR,0);  
	//Listening, wait for the echo
	pinMode(SONAR, INPUT);	
}

// Send out a ping and wait until our handler responds
double findDistance()
{
	pulseLength = INVALID;	
	while(true)
	{
		// Send out a ping and wait for a valid pulse length to be set by the call back
		if( pulseLength == INVALID )
		{
			ping();	
		}
		// Once the pulse length is valid compute the distance to the target
		else
		{	
			// Distance the pulse travelled there and back in that time is: 
			// time multiplied by the speed of sound (mm/s) 
			double distance = (pulseLength * 0.340290) / 2;
			if( distance < 10 )
				return INVALID;
			return distance;
		}
		usleep(10);		
	}	
}

// Stop and check the distance to the target, if its less then 
// increase our feel good factor about the measurement
State GetDistance( State state, double target )
{
	double distance = findDistance();	
	
	if( distance != INVALID )
	{
		//double leftDistance = leftCount * 10.52;
		//double rightDistance = rightCount * 10.52;
		//printf("Distance: %6.2fmm\t  %d secs\t", distance, pulseLength );
		//printf("Left: %6.2fmm\tRight: %6.2fmm\n",leftDistance, rightDistance);			
		if( distance < target )
		{			
			Stop();
			printf("IR Sensor %d\n",digitalRead(SENSOR));
			printf("Target %6.2fmm\tDistance: %6.2fmm\tState %d\n",target, distance, state );
			sleep(1);							
			return IncreaseState(state);
		}
	}	
	return DecreaseState(state);
}
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
int main(int argc, char** argv) 
{
	// GPIO access needs to be root 
	if(geteuid() != 0)
	{
		fprintf(stderr, "Error: requires root to run (sudo?).\n");   
		exit(-1);
	}    	

	// Set up Wiring Pi to use native GPIO numbering
	wiringPiSetup();

	// Setup our tell-tale LEDs
	pinMode (LED, OUTPUT);
	//pullUpDnControl (LED, PUD_DOWN);

	// Setup our control buttons
	pinMode (BUTTON, INPUT);
	pullUpDnControl (BUTTON, PUD_UP);  

	// Create PWM objects for our motors
	int p = softPwmCreate(RIGHT_MOTOR_FWD, 0, 255);
	int q = softPwmCreate(RIGHT_MOTOR_BWD, 0, 255);
	int a = softPwmCreate(LEFT_MOTOR_FWD,  0, 255);
	int b = softPwmCreate(LEFT_MOTOR_BWD,  0, 255); 
	 
	if( (p + q + a + b) != 0 ) {
	  fprintf(stderr, "Error setting PWM.\n");
	  flashLED( 5, 250 ); 
	  exit(-1);
	}
	
	// Set call back for left encoder
	wiringPiISR (ENCODER_LEFT, INT_EDGE_RISING,  &countLeftEncoder);
	// Set call back for right encoder
	wiringPiISR (ENCODER_RIGHT, INT_EDGE_RISING,  &countRightEncoder); 	
	// Set call back for echoStart seen
	wiringPiISR (SONAR, INT_EDGE_RISING,  &echoStart);   	
	// Set call back for ir sensor switching off
	wiringPiISR (SENSOR, INT_EDGE_FALLING,  &done);   

	pinMode (SENSOR, INPUT); 

	// To allow us to simply press a key without Enter we set our terminal to RAW
	// and we save the original settings to restore them on exit
	struct termios oldSettings, newSettings;
	tcgetattr( fileno( stdin ), &oldSettings );
	newSettings = oldSettings;
	newSettings.c_lflag &= (~ICANON & ~ECHO);
	tcsetattr( fileno( stdin ), TCSANOW, &newSettings );   
	
	// Disable all tell-tale LEDs
	setLed( 0 );

	// This is our main menu from which we launch our challenge functions
	presses = 0;	
	while (inMenu) 
	{	 
		blinkLED(presses, 500);  
	
		if (digitalRead(BUTTON) == LOW)
			countPresses( );
			
		if (launch)
		{
			// Launch the function and reset the number of presses for the menu and launch flag
			launchFunction(presses);
			launch = false;
			presses = 0;
		}
	  
		char key_state = getKey();  
		if(key_state == 'x' ) 
			inMenu = false;

	}

	// Say "good night" Lucy
	flashLED( 2, 1000 );
	// Put back the terminal settings as they were
	tcsetattr( fileno( stdin ), TCSANOW, &oldSettings );
	exit(0);
}

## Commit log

2015-07-19 Created work-in-progress branch and added first hardware files and images
    [TractorBot.fzz]
2015-07-26 Licence boiler plate
2015-10-04 Old code folder removed, now replaced with software folder. Edits to main README.md and hardware.md
    [TractorBot.cpp]
